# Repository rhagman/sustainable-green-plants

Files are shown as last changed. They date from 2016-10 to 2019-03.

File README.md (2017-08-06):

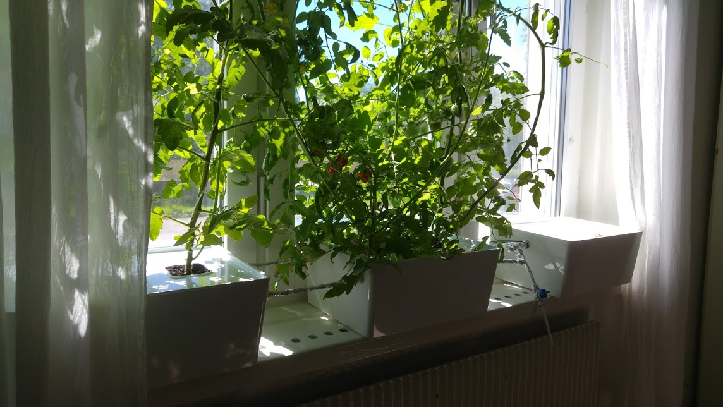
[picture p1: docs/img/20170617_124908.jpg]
Basic kit Small and modular DIY kit


The development is currently in alpha, but you can of course try it out.

# Introduction
The goal of this repository is to contain all the information needed to
[get](#how-to-get), [build](#how-to-build) and [run](#how-to-run) an high
pressure aeroponics. The idea is to design a cheap modular system that anyone
can use at home for sustainable food production.

# Small and modular DIY kit
Using a small and modular DIY kit can be very useful for growing herbs or other
small plants you prefer. The parts cost around USD 57 (SEK 500) and to run the
basic kit in the window costs about USD 0.11 (SEK 1) per month. If you, like
me, live in Sweden and need some extra light during winter, you can use LEDs
which can cost you USD 1 (SEK 9) per month - a price example of using LEDs from
IKEA.

## How to get
Go to the [wiki](https://github.com/rhagman/sustainable-green-plants/wiki) and
look under the [small and modular DIY
kit](https://github.com/rhagman/sustainable-green-plants/wiki/Small-and-modular-DIY-kit)
section.

## How to build
Follow the [guide in google photos](https://goo.gl/photos/72PxL2RxAaFRTnkQA).
If you have any questions or need help, you can just comment in the album.

## How to run
In short: mix 10g of
[nutrients](https://github.com/rhagman/sustainable-green-plants/wiki/List-of-materials)
into 4L of water and add it to the vases. Then, you add about 4L of water a
week to the vase and once a month you instead add 4L of the same nutrient mix
as before. [Here](https://goo.gl/photos/Q2npofLhUkbP5R9r5) is an album that I
add pictures to as I'm using it.

# Large and modular DIY kit
Using a large and modular DIY kit can be very useful for growing most plants
that you prefer, this is what you should use for sustainable food production.

## How to get
Go to the [wiki](https://github.com/rhagman/sustainable-green-plants/wiki) and
look under the [large and modular DIY
kit](https://github.com/rhagman/sustainable-green-plants/wiki/Large-and-modular-DIY-kit)
section.

## How to build
Follow the [guide in google photos](https://goo.gl/photos/Ph61oP1ydN2B55Q58).
If you have any questions or need help, you can just comment in the album.

# Software instructions
* arduino_sketch - contains the arduino sketch file which you need to upload to
your arduino uno.

# Get involved
Join our [slack](https://sgplants.slack.com) by sending me a message and I'll
send you an invitation! There have been a lot of different components that have
been tested to make these DIY kits, you can find a [list of
materials](https://github.com/rhagman/sustainable-green-plants/wiki/List-of-materials)
for what has been tested. If you think something should be changed with the
kits, then get in contact with me and we can update the kits!

# License
MIT

# Sustainable Green Plants


[imgur](https://sgplants.imgur.com/) |
[facebook](https://www.facebook.com/sgplants/) |
[twitter](https://twitter.com/sg_plants) |
[blogger](https://sustainablegreenplants.blogspot.se) |
[tumblr](https://sustainablegreenplants.tumblr.com) |
[instagram](https://www.instagram.com/sustainablegreenplants/)

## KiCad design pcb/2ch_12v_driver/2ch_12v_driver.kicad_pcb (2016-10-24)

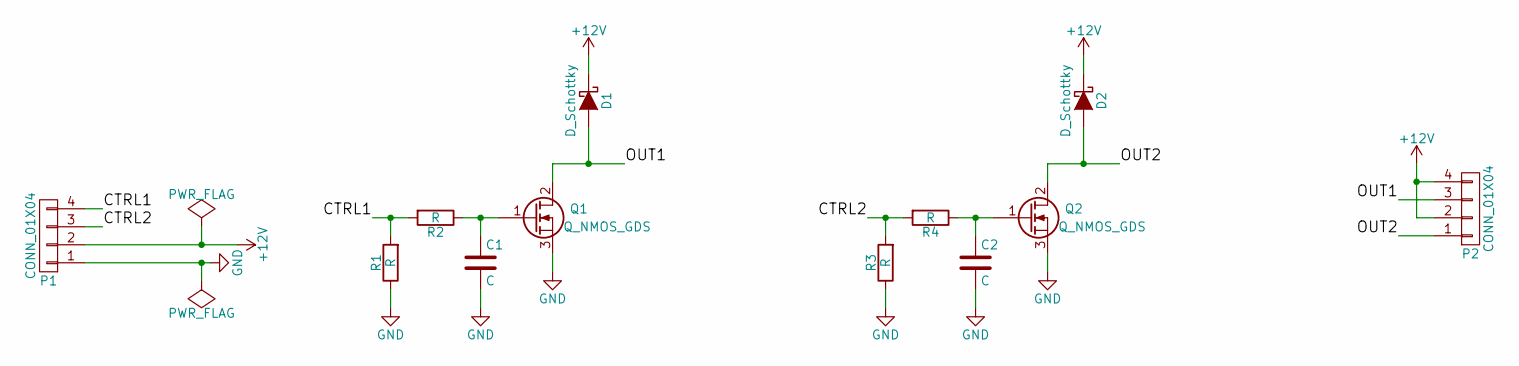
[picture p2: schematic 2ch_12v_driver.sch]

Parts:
C1, C2: C; C_Disc_D6_P5
D1, D2: D_Schottky; Diode_DO-41_SOD81_Horizontal_RM10
P1, P2: CONN_01X04; Pin_Header_Straight_1x04
Q1, Q2: Q_NMOS_GDS; TO-220_Neutral123_Vertical
R1, R2, R3, R4: R; Resistor_Horizontal_RM10mm

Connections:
+12V: D1.1 (K), D2.1 (K), P1.2, P2.2, P2.4
/CTRL1: P1.4, R1.2, R2.2
/CTRL2: P1.3, R3.2, R4.2
/OUT1: D1.2 (A), P2.3, Q1.2 (D)
/OUT2: D2.2 (A), P2.1, Q2.2 (D)
GND: C1.2, C2.2, P1.1, Q1.3 (S), Q2.3 (S), R1.1, R3.1
unnamed: C1.1, Q1.1 (G), R2.1
unnamed: C2.1, Q2.1 (G), R4.1

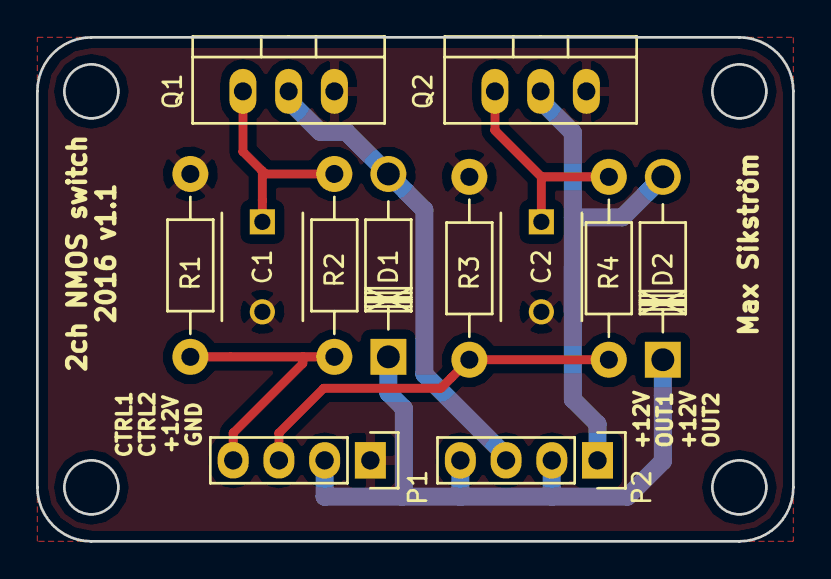
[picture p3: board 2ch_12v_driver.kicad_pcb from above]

Board: 2 copper layers, 42.0 x 28.0 mm, 12 parts (0 on the bottom side), 8 nets.

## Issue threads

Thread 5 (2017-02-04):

Basic kit - Irrigation

rhagman, 2017-02-04:
As a developer, I would like to be able to build the irrigation part of the basic aeroponics kit.

Suggestion: Document in the wiki where to buy and how-to build the irrigation part of the Basic kit.

rhagman, 2017-03-20:
Almost done with the documentation in the wiki. I realized that I ordered the wrong "pcb terminal block", so I need to update that part in the wiki. The how-to is done at [imgur](http://imgur.com/a/wkV9c). After updating the wiki with the correct "pcb terminal block" link and some tool updates that I found when I was building the thing, I can then close this issue. Yay! 🐙

rhagman, 2017-03-20:
I just realized that the "pcb terminal block" part belongs to another issue. So I can close this one now! To build the irrigation part of the build, go to the [wiki](https://github.com/rhagman/sustainable-green-plants/wiki/Small-and-modular-DIY-kit) to get the list of materials and [imgur](http://imgur.com/a/wkV9c) for the how-to. Happy building!

Closed 2017-03-20.

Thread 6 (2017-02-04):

Basic kit - Electronics

rhagman, 2017-02-04:
As a developer, I would like to build the electronics part of the basic kit.

Suggestion: Document in the wiki where to buy and how-to build the electronics part of the Basic kit.

rhagman, 2017-03-20:
Almost done with the documentation in the [wiki](https://github.com/rhagman/sustainable-green-plants/wiki/Small-and-modular-DIY-kit). I realized that I ordered the wrong "pcb terminal block", so I need to update that part in the wiki. The how-to is done at [imgur](http://imgur.com/a/wkV9c). After updating the wiki with the correct "pcb terminal block" link and some tool updates that I found when I was building the thing, I can then close this issue.

averageanomaly, 2017-04-15:
Hey! I was hoping to find where you got your pcb board. Your project looks great!

mattiasr, 2017-04-15:
A co-worker helped design and printed with https://www.itead.cc

rhagman, 2017-04-15:
You can find the pcb file here: https://github.com/rhagman/sustainable-green-plants/tree/master/pcb/2ch_12v_driver and then upload it to the site @mattiasr mentioned.

Closed 2017-05-25.

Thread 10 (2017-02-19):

NTP integration

cchance27, 2017-02-19:
Instead of using the reset button to set 20:00 would recommend if theirs memory available to integrate NTPclient to pull the real time, especially since the D1 already has wifi, i mean you can leave the reset and on boot 20:00 but would be cool if the NTPclient synced everything, especially once you move to modular and have perhaps multiple sensors all synced.

http://playground.arduino.cc/Code/NTPclient

rhagman, 2017-07-16:
I'll close this issue and link it to #18 so that we can have this in mind when updating the software. This is probably one of the first features that will be included once we start to work with the software! Thanks for contributing to the project, if you would like to join the development chat, then send message with your email and I'll send you an invite to slack! Have a nice day!

Closed 2017-07-16.

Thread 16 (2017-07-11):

Run and document the usage of the first iteration of the Basic kit.

rhagman, 2017-07-11:
Use the Basic kit and "stress test" it by having dirt as plant holders and light blocker. Run the pump more than needed to stay at max pressure. Don't change the reservoir but simply add water and more nutrients as the levels decrease. Let the plants drink all the liquid in the reservoir and let it dry run for a few days to see how fast the plants take damage and if they can come back after a few days of "dry running".

rhagman, 2017-07-11:
I'll add pictures to google photo and document things related to this issue in this issue. https://goo.gl/photos/Q2npofLhUkbP5R9r5

Things to do:
- [ ] Write some text in google photo to document what the photos show
- [ ] Make a list of things that needs updating now that I know more

rhagman, 2017-09-07:
https://goo.gl/photos/Q2npofLhUkbP5R9r5 concludes the issue.

Closed 2017-09-07.

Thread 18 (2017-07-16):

Software

rhagman, 2017-07-16:
The current software is just a Prof of concept (POC) to get development going. Now that we know a lot more we would like to design the software so that we can facilitate integration with other project.

For example:
* [Home assistant](https://home-assistant.io/), nice to be able to get all the data into it and control everything from a computer or smart phone.
* [Grafana](https://grafana.com/) for graphing and data analysis.
* [Local food nodes](https://localfoodnodes.org/) for buying and selling local produce.

Writing the new software could also make it easier for people to add their own sensors, automation rules etc.

timelf123, 2018-12-18:
I just got bit by the home automation bug and am also starting to research hydro/aeroponics. I'm planning on following your build guide soon and think it would be amazing to package this up into a HA component

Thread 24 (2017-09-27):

Add issues for what is going on and what probably will go on in the project

rhagman, 2017-09-27:
To be more inclusive in the project and help with collaboration, it is nice to have an open place to share what the current plan is for the project. Creating issues and structure them in different projects here in github is probably a good way to do it.

WebbPeter, 2017-09-29:
I agree! It's definitely valuable to cross pollinate (hah) platforms though! Definitely make sure that people on your slack, as well as your general blog know that you want them to participate.

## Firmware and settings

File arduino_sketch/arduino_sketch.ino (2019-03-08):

#include <Arduino.h>
#include <TimeLib.h>  // For timekeeping

// LED pins (PWM pins: 3,5,6,9,10,11 on arduino UNO)
const int PUMP  = 4;  // Pin 4 on arduino maps to D2 on wemos
const int NOZZLE = 5; // Pin 5 on arduino maps to D1 on wemos
const int runInterval = 1;
const int pumpMaxRunTime = 0;

/**
 * Schedule of all settings
 */
int usrSch[3][3] = {
  {0,10,1}, // Spray the roots at a set interval and duration (Default)
  {1,10,1}, // Run the pump (Default)
  {0,10,1}  // Night setting (Default)
};
// Day setting set (0:00-23:00)
int usrSchInd[1][24] = {
  {2,2,2,2,2,2,2,2,2,0,0,0,1,0,0,0,0,0,0,0,0,2,2,2} // Pump at 12:00
};


// Variable for pump
int pumpOn = 0; // 0 off, 1 on
int nozzleInterval = 10; // min interval between nozzle activation >60 == off
int nozzleDuration = 1;  // sec active nozzle <0 == off

// Run preprogrammed setup, oneReport after nozzle on
int runProgram = 1;
int oneReport = 0;

// Time
time_t t = 0;
time_t tDelay = runInterval;

void setup() {
  Serial.begin(9600); // Serial port at 9600 baud

  // Set the time
  setTime(12,0,0,1,1,2014); // hour,min,sec,day,month,year

  // Set pins as outputs
  pinMode(PUMP, OUTPUT);
  pinMode(NOZZLE, OUTPUT);
  pinMode(LED_BUILTIN, OUTPUT); // Pin 13 on arduino and 2 on wemos
  digitalWrite(LED_BUILTIN, LOW);
}

void loop() {
  t = now();
  // Keep working as long as data is in the buffer
  while (Serial.available() > 0) {
    serialControl();
  }
  if (t < tDelay) {
    return;
  }

  if (runProgram == 1) {
    scheduleFromUser();

    /**
     * The scheduling is per hour, but running the pump for that long is
     * unnessesary so have a maximum run time that is less than 60 min.
     */
    if (pumpOn == 1 && minute(t) > pumpMaxRunTime) {
      pumpOn = 0;
    }
    setPump();
  }
  if (nozzleInterval-1 == minute(t) % nozzleInterval) {
    if (nozzleDuration > second(t)) {
      digitalWrite(NOZZLE, HIGH);
      oneReport = 1;
    }
    if (nozzleDuration <= second(t)) {
      digitalWrite(NOZZLE, LOW);
      if (oneReport == 1) {
        oneReport = 0;
        serialReport();
      }
    }
  }

  tDelay = t + runInterval;
}

/*
 * Messages consist of the letter S followed by
 * ,int(0-1),int(0-59),int(0-59)
 * S,0,20,5 (pump,nozzlieInterval,nozzleDuration)
 */
void serialControl()
{
    char c = Serial.read();
    switch (c) {
      case 'S':
      {
        pumpOn = Serial.parseInt();
        nozzleInterval = Serial.parseInt();
        nozzleDuration = Serial.parseInt();

        setPump();
        setNozzle();
        break;
      }
      case 'R':
      {
        serialReport();
        break;
      }
      case 'Q':
      {
        if (runProgram == 1) {
          runProgram = 0;
          break;
        }
        if (runProgram == 0) {
          runProgram = 1;
          break;
        }
        break;
      }
      case 'T':
      {
        int h  = Serial.parseInt(); //First valid integer
        int m  = Serial.parseInt(); //Second valid integer
        int d  = Serial.parseInt(); //Third valid integer
        setTime(h,m,0,d,1,2014);    //hour,min,sec,day,month,year
        t = now();
        tDelay = runInterval;
        break;
      }
    }
}

void scheduleFromUser() {
  // Change every hour
  int x = hour(t); // 0-23
  int z = usrSchInd[0][x];

  pumpOn = usrSch[z][0];
  nozzleInterval = usrSch[z][1];
  nozzleDuration = usrSch[z][2];
}

/**
 * Turn the pump on or off depending on the value of the global variable pumpOn.
 */
void setPump() {
  if (pumpOn == 1) {
    digitalWrite(PUMP, HIGH);
  }
  if (pumpOn == 0) {
    digitalWrite(PUMP, LOW);
  }
}

void setNozzle()
{
  if (nozzleDuration == 0) {
    digitalWrite(NOZZLE, LOW);
  }
}

void serialReport() {
  String reportValues;

  reportValues = "Settings:\n";
  reportValues = "Pump(0=off, 1=on):      ";
  reportValues = reportValues + pumpOn;
  reportValues = reportValues + "\nMinutes between sprays: ";
  reportValues = reportValues + nozzleInterval;
  reportValues = reportValues + "\nSeconds of spray:       ";
  reportValues = reportValues + nozzleDuration;

  reportValues = "-- Report ----\n" + timeReport() + reportValues;
  Serial.println(reportValues);
}

String timeReport() {
  String timeString;

  timeString = "Time(dd:hh:mm:ss):      ";
  timeString = timeString + day(t);
  timeString = timeString + ":";
  timeString = timeString + hour(t);
  timeString = timeString + ":";
  timeString = timeString + minute(t);
  timeString = timeString + ":";
  timeString = timeString + second(t);
  timeString = timeString + "\n";

  return timeString;
}

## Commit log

2015-08-16 Added the arduino file to the project
2016-01-17 Add 3d-printing folder, stl file and update README
    The folder will hold all 3d-printed related stuff. I would like to be able to
    build the systemes with or without a 3d-printer. Upload the stl-file for the
    pet-connector.
    [pet_connector.stl]
2016-09-04 Move arduino dir
    The name of the directory and sketch file needs to be the same.
    Otherwise the arduino IDE will complain.
2016-10-22 Move arduino file and update measure interval
    The arduino file should be within a directory with the same name as the .ino file. Right now I do not care about the measure interval so set it to one hour.
2016-10-22 Clean up things no longer needed
    I've decided to clean up some unused things since my main focus now is to
    get a useful prototype up and running.
    [pet_connector.stl]
2016-10-23 Implement good default behavior
    After uploading the sketch to the Arduino you should be able to just plug
    everything in and it should work well for a simple system.
    Assume that the time is 10:00 and run the pump every day at 10:00 and
    20:00 for at most one minute. Spray every 10 min for 2 sec each.
    Refactor some of the horrible code. Next step will probably be to add unit
    and integration tests.
2016-10-24 PCB: Add 2ch 12V driver, to power pump from mcu
    To be able to drive a 12V inductive load from a microcontroller like
    Arduino, a driver circuit is needed.
    This adds a two channel with about 5V input (can be anything from NMOS V_th
    voltage to V_gs maximum voltage), to power the output load.
    [2ch_12v_driver-B.Cu.gbl, 2ch_12v_driver-B.Mask.gbs, 2ch_12v_driver-B.SilkS.gbo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]
2017-02-06 Remove pH measurement functionality
    The focus is not to have a lot of sensors at the moment. Building for
    d1_mini got errors for eeprom so this is the perfect time to remove some
    unused code. Later in the project I will re-add the functionality.
    [arduino_sketch.ino]
2017-02-06 Use PlatformIO and Travis
    PlatformIO seems like a good tool to use since I easily can build for
    Arduino UNO and D1 mini. As well as other platforms in the future. Nice
    support for it in the Atom IDE that I have started to like more and more.
    Also, implement the use of Travis.
2017-03-04 Update default settings
    We now run the system with the same schedule and settings all the time.
    When the microcontroller starts it assumes that the time is 20:00 and it
    runs the pump. Then every 20min it sprays the roots for 2s.
    Also make some style changes to the code and clean up a k = k++ wtf...
2018-01-31 Breaking change: change pin output
    So that it works nicely with arduino uno and wemos. Also, remove legacy
    code that is no longer needed.
    [arduino_sketch.ino]
2019-03-08 Default values for nozzles and pump duration
